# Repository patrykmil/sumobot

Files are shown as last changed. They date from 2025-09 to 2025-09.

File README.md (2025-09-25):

### Config:

Konfiguracja znajduje się w pliku config.h
Ważne parametry:

- #define FRONT_LINE_SENSOR 0
- #define BACK_LINE_SENSOR 0

należy ustawić 1 lub 0 w zależności od tego czy dany czujnik jest podłączony

- int lineColor = 1;

ustawia kolor linii (1 - czarna, 0 - biała)

Przypisanie pinów znajduje się w pliku main.cpp:

### Platformio:

Build

```sh
pio run
```

Upload

```sh
pio run --target upload
```

Monitor

```sh
pio device monitor
```

Upload and Monitor

```sh
pio run --target upload --target monitor
```

### Śruby:

| Rozmiar | Ilość | Elementy |
| --- | ----- | --- |
| 3x8 | 4 | 1,4 |
| 2.5x6 | 4 | 4,arduino uno |
| 3x16 | 4 | 2,3 |
| 3x30 | 4 | 1,motor |
| 4x12 | 2 | 1,tylnie kółko |
| 2x12 | 2-4 | 1,line finder |
| 4x10 | 2 | 1,5 |
| 3x16 | 2 | 5,6,8,distance sensor |
| 4x12 | 2 | 1,7 |
| 3x10 | 2 | 7,8,distance sensor |
| 3x16 | 4-10  | 1,2 |
| 4x16 | 0-2 | 2,9 |

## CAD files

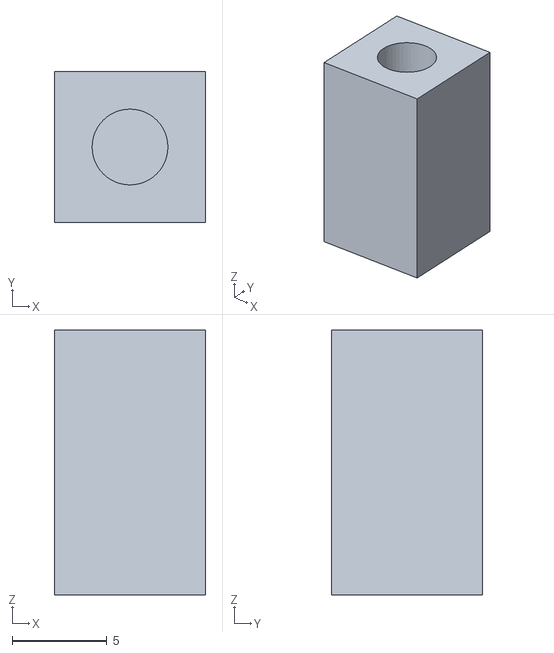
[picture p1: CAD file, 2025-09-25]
model/9_blokoda_baterie.stl
8.00 x 8.00 x 14.0

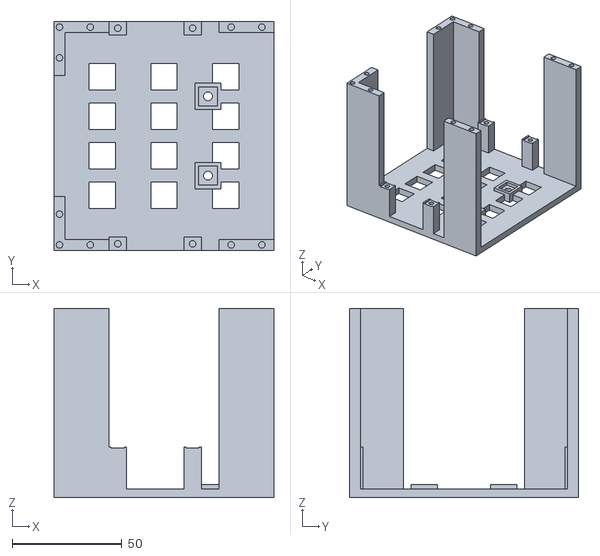
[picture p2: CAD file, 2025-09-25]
model/2_dach.stl
100.0 x 104.0 x 86.0

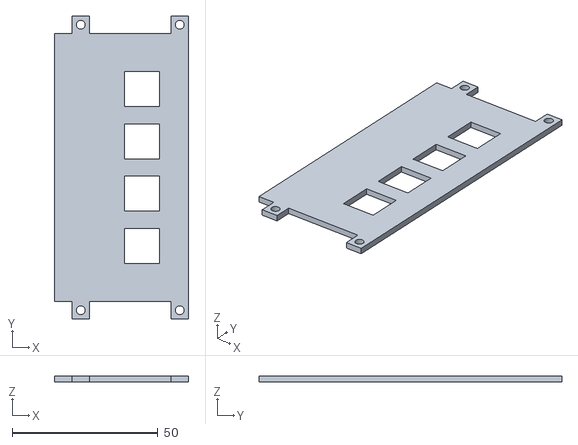
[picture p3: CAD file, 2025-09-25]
model/3_oslona_baterie.stl
46.0 x 104.0 x 2.00

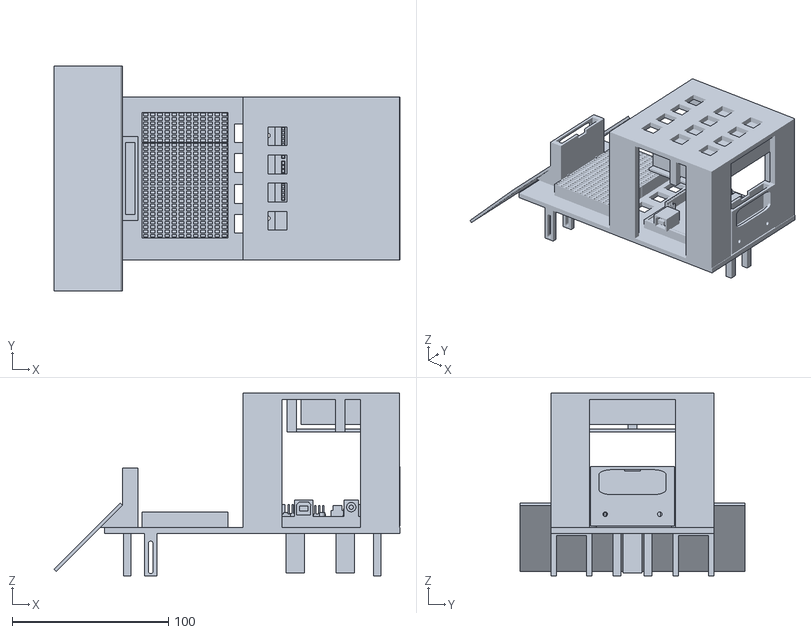
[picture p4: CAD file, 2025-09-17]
model/cały_złożony.stl
221.3 x 144.0 x 117.0

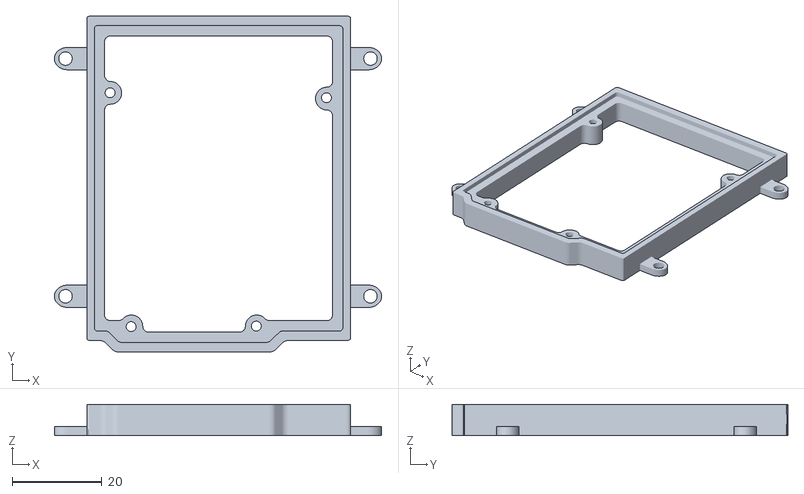
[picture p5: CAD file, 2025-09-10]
model/4_ramka_arduino.stl
73.0 x 74.9 x 6.99

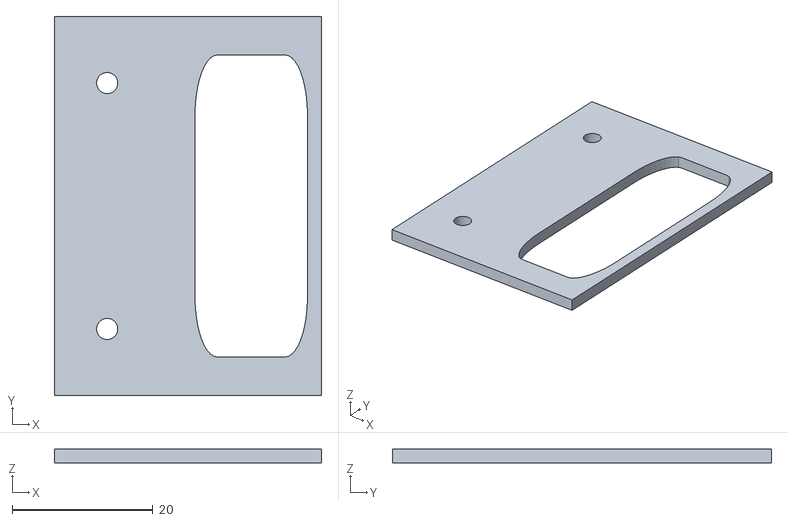
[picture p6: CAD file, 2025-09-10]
model/8_distance_sensor_brzuch.stl
38.0 x 54.0 x 2.00

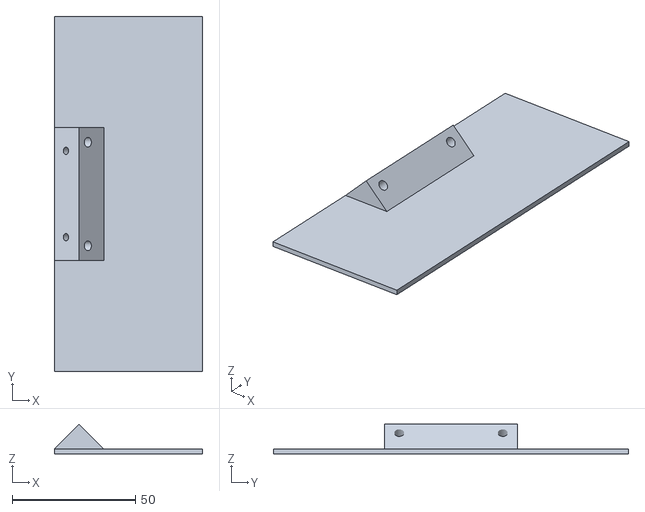
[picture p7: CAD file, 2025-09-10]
model/5_spychacz.stl
60.0 x 144.0 x 12.0

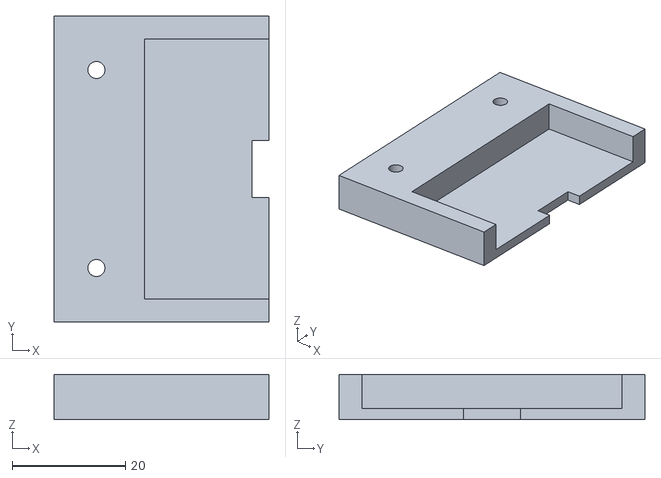
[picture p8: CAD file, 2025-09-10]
model/7_distance_sensor_tylni_plecy.stl
38.0 x 54.0 x 8.00

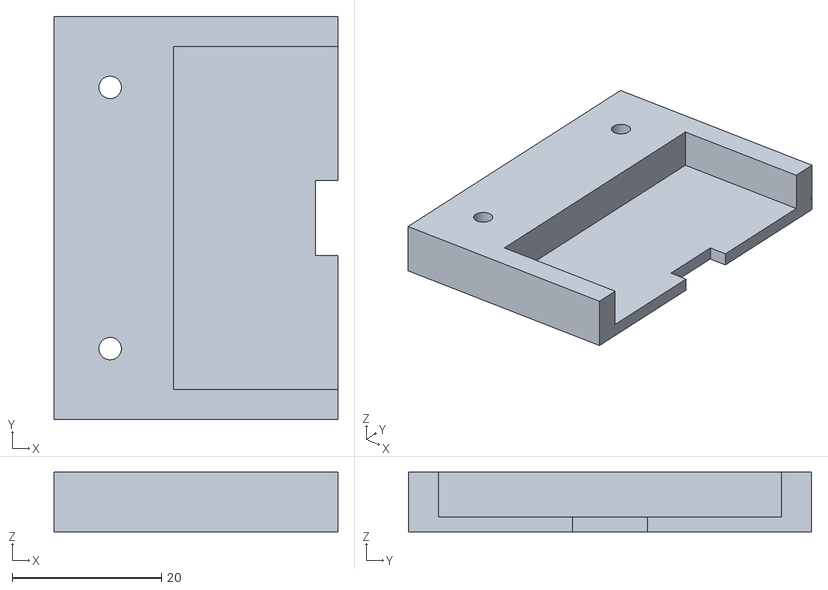
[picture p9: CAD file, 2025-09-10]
model/6_distance_sensor_przedni_plecy.stl
38.0 x 54.0 x 8.00

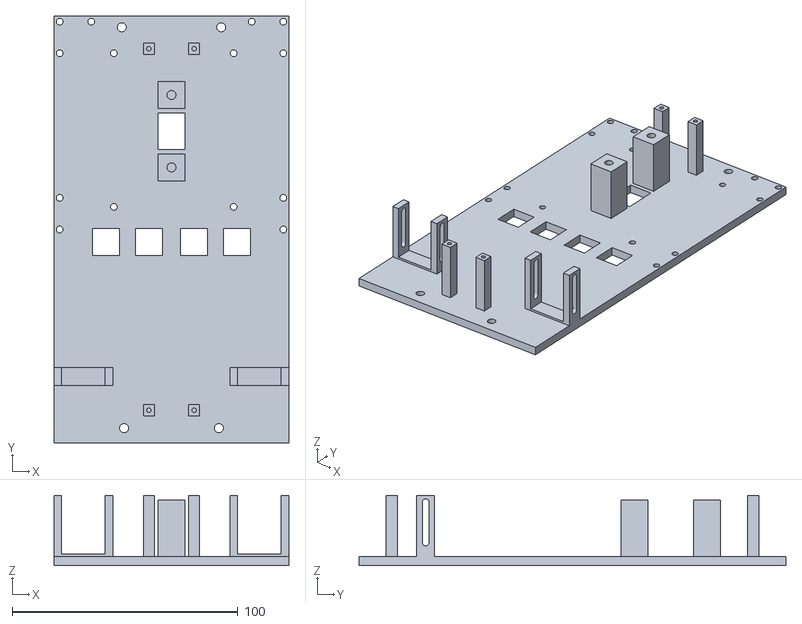
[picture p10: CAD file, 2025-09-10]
model/1_podstawa.stl
104.0 x 189.0 x 31.0

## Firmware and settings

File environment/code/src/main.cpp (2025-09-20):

#include <Arduino.h>
#include <config.h>
#include <move.h>
#include <phases.h>
#include <sensors.h>

SumoConfig config;
SumoState currentState;
unsigned long stateStartTime = 0;
int SPEED = 80;
int DIRECTION = 1;
int LINE_COLOR = 1;
int SCAN_DISTANCE = 25;

// Motor pins definition
const int LEFT_IN1 = 12;
const int LEFT_IN2 = 13;
const int LEFT_PWM = 11;
const int RIGHT_IN1 = 8;
const int RIGHT_IN2 = 9;
const int RIGHT_PWM = 10;

// Sensor pins definition
const int LINE_FRONT_PIN = 2;
const int LINE_BACK_PIN = 3;
const int DIST_BACK_TRIG = 4;
const int DIST_BACK_ECHO = 5;
const int DIST_FRONT_TRIG = 6;
const int DIST_FRONT_ECHO = 7;

void debug() {
    Serial.print("\nState: ");
    Serial.print(currentState == SCANNING    ? "SCANNING"
                 : currentState == ATTACKING ? "ATTACKING"
                                             : "RETREATING");
    Serial.print("\nFront Distance: ");
    Serial.print(getDistanceFront());
    Serial.print("\nBack Distance: ");
    Serial.print(getDistanceBack());
    Serial.print("\nEnemy Detected: ");
    Serial.print(isEnemyDetected() ? "Yes" : "No");
    Serial.print("\nClosest Enemy: ");
    Serial.print(getClosestEnemyDistance());
    Serial.print("\nDirection: ");
    Serial.print(getEnemyDirection());
#if FRONT_LINE_SENSOR
    Serial.print("\nLine front: ");
    Serial.print(isLineFront() ? "Yes" : "No");
#endif
#if BACK_LINE_SENSOR
    Serial.print("\nLine back: ");
    Serial.print(isLineBack() ? "Yes" : "No");
#endif
    Serial.print("\n\n-------------------");
    delay(1000);
}

void setup() {
    SPEED = config.scanSpeed;
    LINE_COLOR = config.lineColor;
    SCAN_DISTANCE = config.enemyDetectionDistance;

    pinMode(LEFT_IN1, OUTPUT);
    pinMode(LEFT_IN2, OUTPUT);
    pinMode(LEFT_PWM, OUTPUT);
    pinMode(RIGHT_IN1, OUTPUT);
    pinMode(RIGHT_IN2, OUTPUT);
    pinMode(RIGHT_PWM, OUTPUT);

    pinMode(LINE_FRONT_PIN, INPUT);
    pinMode(LINE_BACK_PIN, INPUT);

    pinMode(DIST_FRONT_TRIG, OUTPUT);
    pinMode(DIST_FRONT_ECHO, INPUT);
    pinMode(DIST_BACK_TRIG, OUTPUT);
    pinMode(DIST_BACK_ECHO, INPUT);

    analogWrite(LEFT_PWM, config.scanSpeed);
    analogWrite(RIGHT_PWM, config.scanSpeed);

#if DEBUG
    Serial.begin(9600);
    Serial.println("Sumo Robot Initialized");
    Serial.println("-------------------");
#endif

    // delay(5000);
}

void loop() {
    if (isOnLine() && currentState != RETREATING) {
        currentState = RETREATING;
        stateStartTime = millis();
    }

    switch (currentState) {
        case SCANNING:
            scan();
            break;

        case ATTACKING:
            attack();
            break;

        case RETREATING:
            retreat();
            break;
    }

#if DEBUG
    debug();
#endif

    // delay(20);
}

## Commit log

2025-09-10 Add 3d models for printing
    [cały_złożony.stl, dach.stl, distance_sensor_brzuch.stl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]
2025-09-11 Change attack phase to flip upon detecting enemy in the back
    [main.cpp]
2025-09-16 Update roof
    [dach.stl, osona_baterie.stl]
2025-09-17 Add hardware components table in readme
    [1_podstawa.stl, 2_dach.stl, 3_oslona_baterie.stl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]
2025-09-17 Update models
    [3_oslona_baterie.stl, cały_złożony.stl]
2025-09-20 Update screw size
2025-09-25 Turn on front line sensor
2025-09-25 Update model
    [2_dach.stl, 3_oslona_baterie.stl, 9_blokoda_baterie.stl]
